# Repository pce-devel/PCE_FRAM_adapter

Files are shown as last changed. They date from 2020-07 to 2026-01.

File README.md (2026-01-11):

# FRAM converter boards

The PC Engine series of systems has a different game-save storage system than most people
these days have gotten used to.  It used a 2KB static RAM.  This wasn't in the cartridges
themselves; initially, it was sold as pat of an add-on to the system: The Tennokoe 2,
"Voice from Heaven".  In later systems like the Duo series, it would be integrated into
the system unit, yet still be limited to 2KB static RAM.

You're probably thinking, "Static RAM is volatile - it loses its contents when the power
is shut off", and you'd be right.  There really weren't any non-volatiole options at the
time.  Instead, they used batteries or large capacitors to apply continuous power to the
memory, so that it would not lose its contents.  In the case of the Tennokoe 2, 2 "AA"
cells were used; in the case of the Duo, a large capacitor was used.

I have lost a few game saves on my Duo because I failed to turn the system on for a period
of time long enough to lose its contents... probably about 1 to 2 weeks.

Because of this, I was inspired to replace the SRAM with modern FeRAM to make it
non-volatile.  But the Duo is a tighter-packed PC board with surface-mount chips, so I felt it
was easier to first test the idea on the Tennokoe 2, which uses a DIP SRAM chip.

I have followed up with a design for a flex PCB to use with surface-mount chips in order to
be suitable for my Duo, and it also works well.

I chose to use the Cypress FM16W08 chip, which can handle 5V, has timing which is
equal to or better than the SRAM it is replacing, and has a similar pinout.  But I still
needed to make adapter boards (which is what this repository is all about).

As the FeRAM is rated for 100 trillion read/write cycles, there is no
concern about lifetime under the usage in this application.

I designed the boards using the free version of EAGLE (2-layer, less than 100mm
on both X- and Y-axes).  The gerbers are included in this repository, in case you
want to get your own set made.

## Assembly/installation instructions for the FRAM-DIP board for the Tennokoe 2:

https://github.com/dshadoff/PCE_FRAM_adapter/blob/master/FRAM-DIP-assembly.md

## Assembly/installation instructions for the FRAM-SOIC board for the Duo and other machines:

https://github.com/dshadoff/PCE_FRAM_adapter/blob/master/FRAM-SOIC-assembly.md

## UPDATE: A new board for use with the PCE Shuttle Backup Memory

The Shuttle's board was designed using KiCAD. While this board is separate and distinct from
the board for the Tennokoe 2, the installation instructions are similar (sorry, but I don't
have pictures)

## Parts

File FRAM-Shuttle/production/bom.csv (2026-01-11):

Designator | Footprint | Quantity | Value | LCSC Part #
J1 | PinHeader_2x03_P2.00mm_Vertical | 1 | Conn_02x03_Odd_Even
R1, R2 | 0805 | 2 | 100K
U1 | SOIC-28W_7.5x17.9mm_P1.27mm | 1 | FM16W08-SG
U2 | DIP-24_18.0mmx34.29mm_W15.24mm | 1 | 6116

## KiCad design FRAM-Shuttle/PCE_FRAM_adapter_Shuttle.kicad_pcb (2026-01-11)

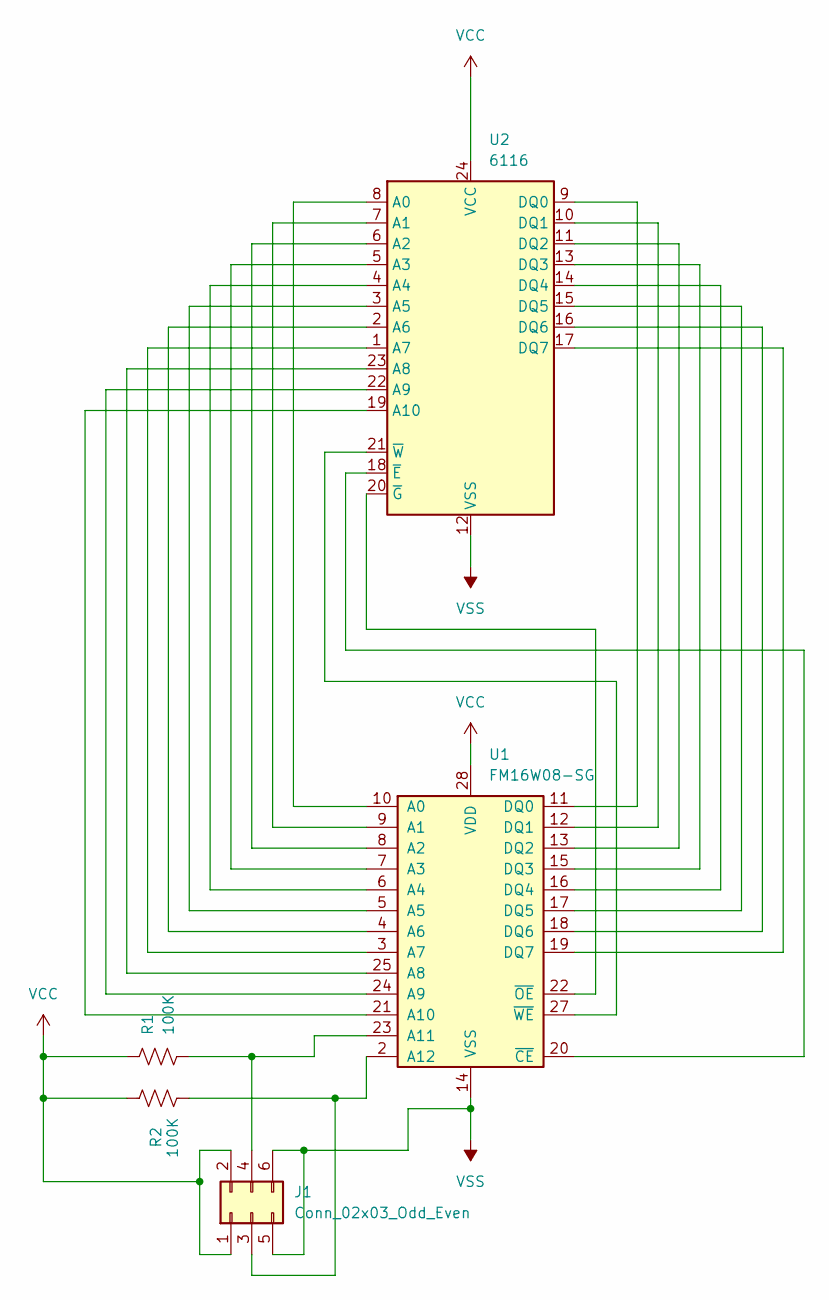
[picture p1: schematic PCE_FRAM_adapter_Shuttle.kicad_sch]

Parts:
J1: Conn_02x03_Odd_Even; PinHeader_2x03_P2.00mm_Vertical
R1, R2: 100K; R_0805_2012Metric_Pad1.20x1.40mm_HandSolder
U1: FM16W08-SG; SOIC-28W_7.5x17.9mm_P1.27mm
U2: 6116; DIP-24_18.0mmx34.29mm_W15.24mm

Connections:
unnamed: J1.3, R2.2, U1.2 (A12)
unnamed: J1.4, R1.2, U1.23 (A11)
unnamed: U1.10 (A0), U2.8 (A0)
unnamed: U1.9 (A1), U2.7 (A1)
unnamed: U1.8 (A2), U2.6 (A2)
unnamed: U1.7 (A3), U2.5 (A3)
unnamed: U1.6 (A4), U2.4 (A4)
unnamed: U1.5 (A5), U2.3 (A5)
unnamed: U1.4 (A6), U2.2 (A6)
unnamed: U1.3 (A7), U2.1 (A7)
unnamed: U1.25 (A8), U2.23 (A8)
unnamed: U1.24 (A9), U2.22 (A9)
unnamed: U1.21 (A10), U2.19 (A10)
unnamed: U1.11 (DQ0), U2.9 (DQ0)
unnamed: U1.12 (DQ1), U2.10 (DQ1)
unnamed: U1.13 (DQ2), U2.11 (DQ2)
unnamed: U1.15 (DQ3), U2.13 (DQ3)
unnamed: U1.16 (DQ4), U2.14 (DQ4)
unnamed: U1.17 (DQ5), U2.15 (DQ5)
unnamed: U1.18 (DQ6), U2.16 (DQ6)
unnamed: U1.19 (DQ7), U2.17 (DQ7)
unnamed: U1.20 (~CE), U2.18 (~E)
unnamed: U1.22 (~OE), U2.20 (~G)
unnamed: U1.27 (~WE), U2.21 (~W)
VCC: J1.1, J1.2, R1.1, R2.1, U1.28 (VDD), U2.24 (VCC)
VSS: J1.5, J1.6, U1.14 (VSS), U2.12 (VSS)

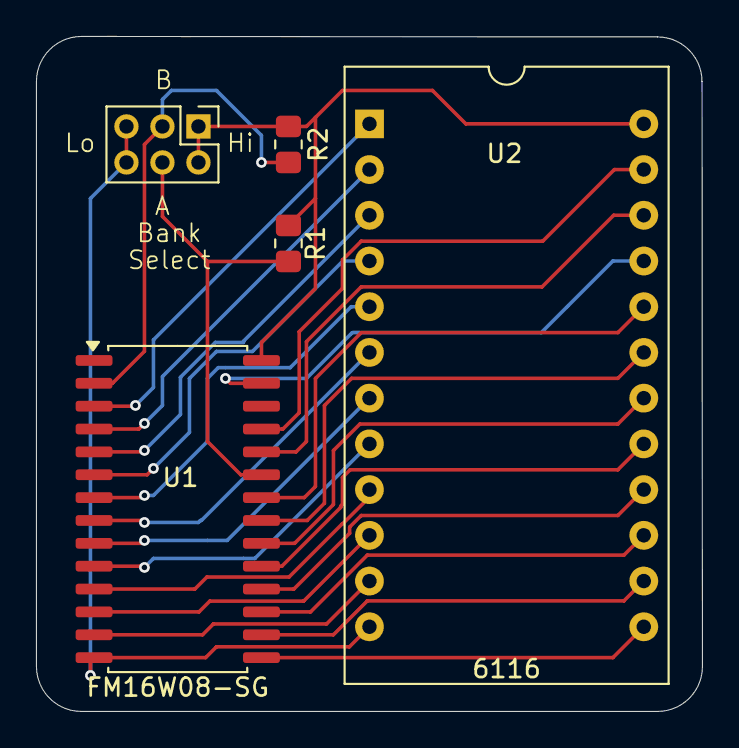
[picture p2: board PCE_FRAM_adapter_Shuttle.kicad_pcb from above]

Board: 2 copper layers, 37.0 x 37.5 mm, 5 parts (0 on the bottom side), 26 nets.

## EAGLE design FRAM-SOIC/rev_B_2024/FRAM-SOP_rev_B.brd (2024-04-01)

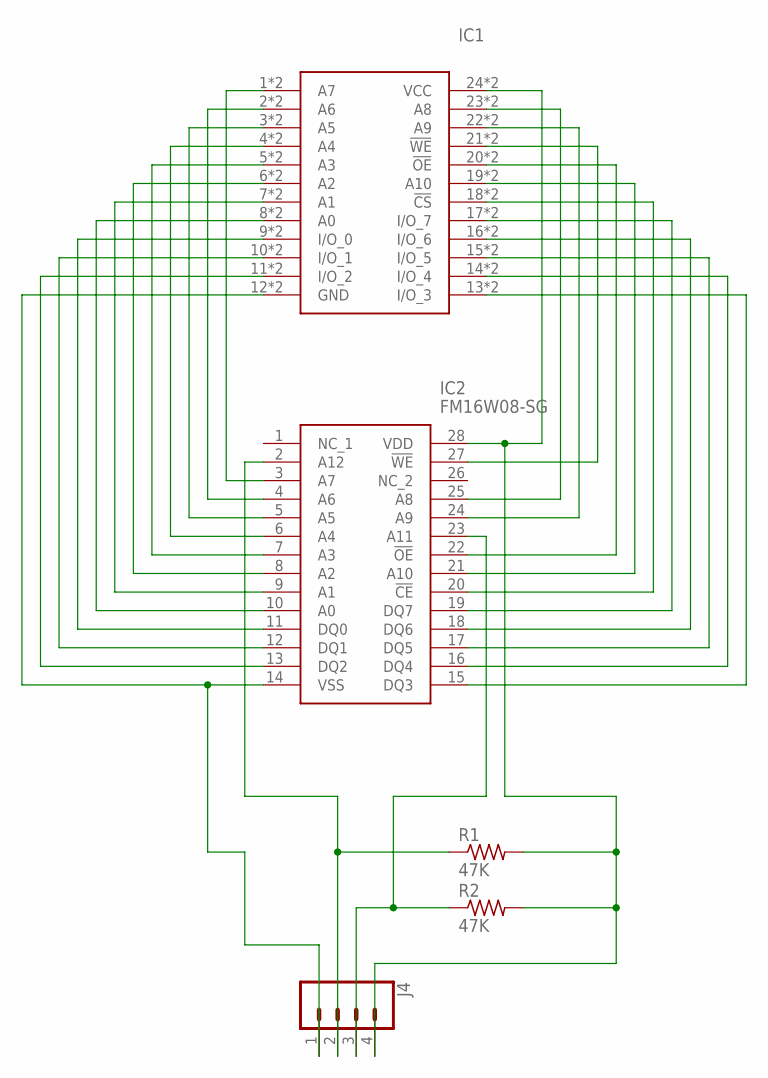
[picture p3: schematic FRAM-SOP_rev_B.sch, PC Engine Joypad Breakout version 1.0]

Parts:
IC1: 6116SOP-CASTELL; CASTELL_SOIC-24N
IC2: FM16W08-SG; SOIC127P1032X267-28N
J4: CONN_04SMD_RA_FEMALE; 1X04_SMD_RA_FEMALE
R1, R2: 47K; R0603

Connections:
unnamed: IC1.24 (VCC), IC1.P$24 (VCC), IC2.28 (VDD), J4.4, R1.2, R2.2
unnamed: IC1.23 (A8), IC1.P$23 (A8), IC2.25 (A8)
unnamed: IC1.22 (A9), IC1.P$22 (A9), IC2.24 (A9)
unnamed: IC1.21 (!WE), IC1.P$21 (!WE), IC2.27 (!WE)
unnamed: IC1.20 (!OE), IC1.P$20 (!OE), IC2.22 (!OE)
unnamed: IC1.19 (A10), IC1.P$19 (A10), IC2.21 (A10)
unnamed: IC1.18 (!CS), IC1.P$18 (!CS), IC2.20 (!CE)
unnamed: IC1.17 (I/O_7), IC1.P$17 (I/O_7), IC2.19 (DQ7)
unnamed: IC1.16 (I/O_6), IC1.P$16 (I/O_6), IC2.18 (DQ6)
unnamed: IC1.15 (I/O_5), IC1.P$15 (I/O_5), IC2.17 (DQ5)
unnamed: IC1.14 (I/O_4), IC1.P$14 (I/O_4), IC2.16 (DQ4)
unnamed: IC1.13 (I/O_3), IC1.P$13 (I/O_3), IC2.15 (DQ3)
unnamed: IC1.1 (A7), IC1.P$1 (A7), IC2.3 (A7)
unnamed: IC1.2 (A6), IC1.P$2 (A6), IC2.4 (A6)
unnamed: IC1.3 (A5), IC1.P$3 (A5), IC2.5 (A5)
unnamed: IC1.4 (A4), IC1.P$4 (A4), IC2.6 (A4)
unnamed: IC1.5 (A3), IC1.P$5 (A3), IC2.7 (A3)
unnamed: IC1.6 (A2), IC1.P$6 (A2), IC2.8 (A2)
unnamed: IC1.7 (A1), IC1.P$7 (A1), IC2.9 (A1)
unnamed: IC1.8 (A0), IC1.P$8 (A0), IC2.10 (A0)
unnamed: IC1.9 (I/O_0), IC1.P$9 (I/O_0), IC2.11 (DQ0)
unnamed: IC1.10 (I/O_1), IC1.P$10 (I/O_1), IC2.12 (DQ1)
unnamed: IC1.11 (I/O_2), IC1.P$11 (I/O_2), IC2.13 (DQ2)
unnamed: IC2.2 (A12), J4.2, R1.1
unnamed: IC1.12 (GND), IC1.P$12 (GND), IC2.14 (VSS), J4.1
unnamed: IC2.23 (A11), J4.3, R2.1

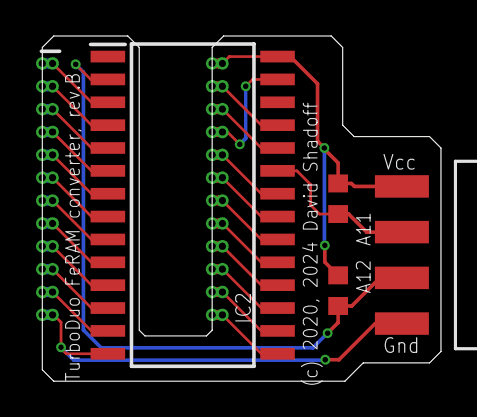
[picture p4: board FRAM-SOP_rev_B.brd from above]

Board: 2 copper layers, 22.1 x 19.2 mm, 5 parts (0 on the bottom side), 26 nets.

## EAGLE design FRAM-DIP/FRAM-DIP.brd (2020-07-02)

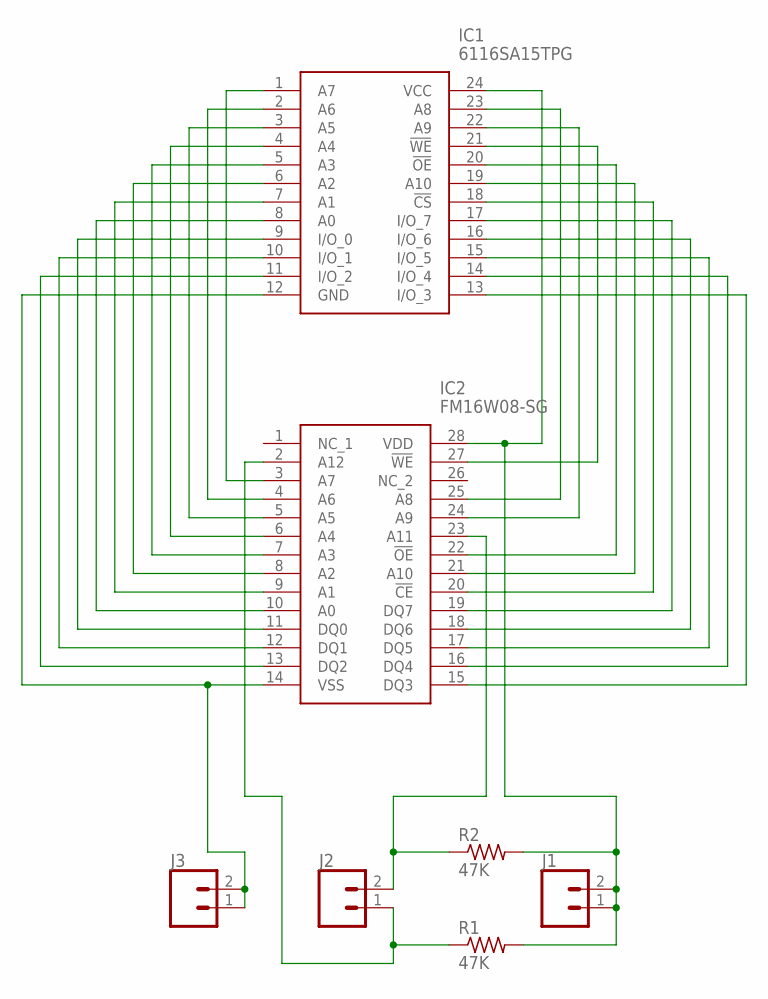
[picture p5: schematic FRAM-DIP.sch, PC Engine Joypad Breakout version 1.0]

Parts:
IC1: 6116SA15TPG; DIP864W51P254L3169H381Q24N
IC2: FM16W08-SG; SOIC127P1032X267-28N
J1, J2, J3: CONN_02; 1X02
R1, R2: 47K; R0805

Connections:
unnamed: IC1.24 (VCC), IC2.28 (VDD), J1.1, J1.2, R1.2, R2.2
unnamed: IC1.23 (A8), IC2.25 (A8)
unnamed: IC1.22 (A9), IC2.24 (A9)
unnamed: IC1.21 (!WE), IC2.27 (!WE)
unnamed: IC1.20 (!OE), IC2.22 (!OE)
unnamed: IC1.19 (A10), IC2.21 (A10)
unnamed: IC1.18 (!CS), IC2.20 (!CE)
unnamed: IC1.17 (I/O_7), IC2.19 (DQ7)
unnamed: IC1.16 (I/O_6), IC2.18 (DQ6)
unnamed: IC1.15 (I/O_5), IC2.17 (DQ5)
unnamed: IC1.14 (I/O_4), IC2.16 (DQ4)
unnamed: IC1.13 (I/O_3), IC2.15 (DQ3)
unnamed: IC1.1 (A7), IC2.3 (A7)
unnamed: IC1.2 (A6), IC2.4 (A6)
unnamed: IC1.3 (A5), IC2.5 (A5)
unnamed: IC1.4 (A4), IC2.6 (A4)
unnamed: IC1.5 (A3), IC2.7 (A3)
unnamed: IC1.6 (A2), IC2.8 (A2)
unnamed: IC1.7 (A1), IC2.9 (A1)
unnamed: IC1.8 (A0), IC2.10 (A0)
unnamed: IC1.9 (I/O_0), IC2.11 (DQ0)
unnamed: IC1.10 (I/O_1), IC2.12 (DQ1)
unnamed: IC1.11 (I/O_2), IC2.13 (DQ2)
unnamed: IC2.2 (A12), J2.1, R1.1
unnamed: IC2.23 (A11), J2.2, R2.1
unnamed: IC1.12 (GND), IC2.14 (VSS), J3.1, J3.2

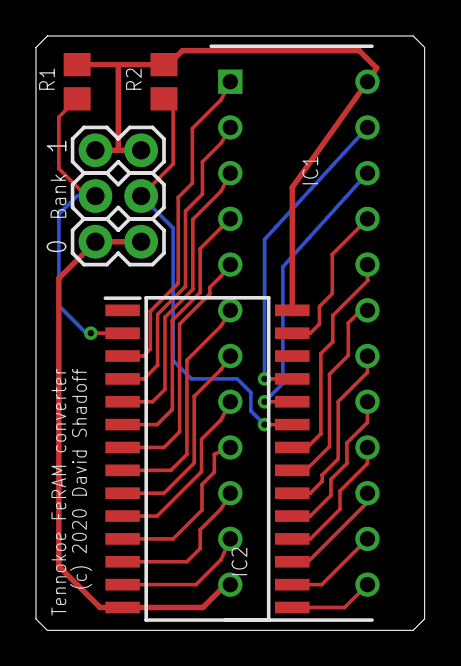
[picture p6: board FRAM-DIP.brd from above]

Board: 2 copper layers, 21.6 x 33.0 mm, 7 parts (0 on the bottom side), 26 nets.

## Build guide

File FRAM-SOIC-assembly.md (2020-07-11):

# FRAM-SOIC converter board installation - TurboDuo

I only have a Duo to demonstrate on, but I'm reasonably certain that the board will fit
other models like the Duo-R and Duo-RX.

The SOIC adapter board is simple enough to install if you are confident in your soldering
skills. But if you are just starting out, you may want to get it installed by somebody
else.

## Preparation:

1. Backup - If you have any game saves in the unit, you will want to back them up somehow.
A Tennokoe Bank card is probably your best option.

2. Open the Machine - Next, turn the unit over, and remove the screws holding the back on.
After removing the screws, turn the Duo back over so it sits as it normally would.  Next,
open the CD lid, and gently wiggle the top plastic shell off of the bottom shell... you may
see that some plastic in the CD drive area; this may be helpful to get some leverage for
gently opening the top (be careful not to touch the lens !)  Also, if your system has had
modifications done on it before, there may be wires leading to some mounting point in the
top shell; be very careful not to put any stress on these as you lift the top shell.

3. Locate the Chip - On the Duo, you will find the SRAM chip in the middle on the
left-right axis, and slightly toward the back on the front-back axis.  It's close to the
voltage regulators with their heatsinks.

Take note of where pin 1 of the chip is.

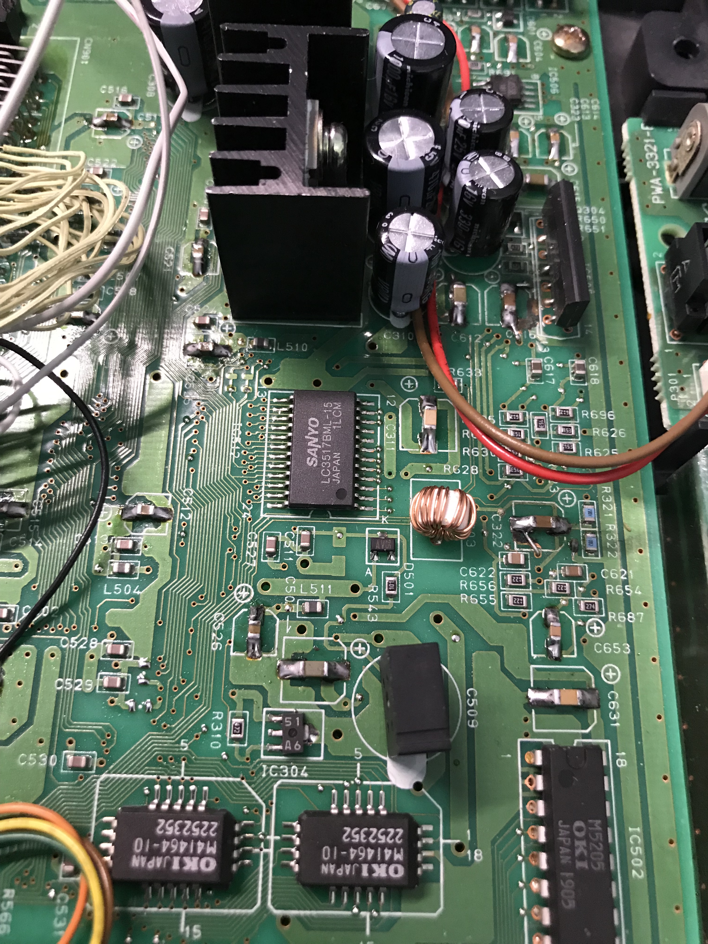
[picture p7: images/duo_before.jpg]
SRAM on Duo


## Desolder the old chip:

This is the most difficult part of the operation, as the chip seems to be held
tightly against the board by some sort of lacquer or glue - and this is why I don't
recommend this upgrade to novices.

1. If you have a hot air station, you may wish to use it to desolder the pins - and weaken
the lacquer/glue bond.

2. If you don't have a hot air station, you should first remove as much solder as possible
from the leads, using a solder wick. As you apply heat on a second pass, you will need to
lift the pins from the pads as well.  Removing the actual chip from the board may require
isopropyl alcohol, but as you try to lift it, be careful not to damage the board or any of
the copper traces !  Once it's off, go back around the pads with the solder wick to clean
them up, and use the alcohol once more to clean the area.

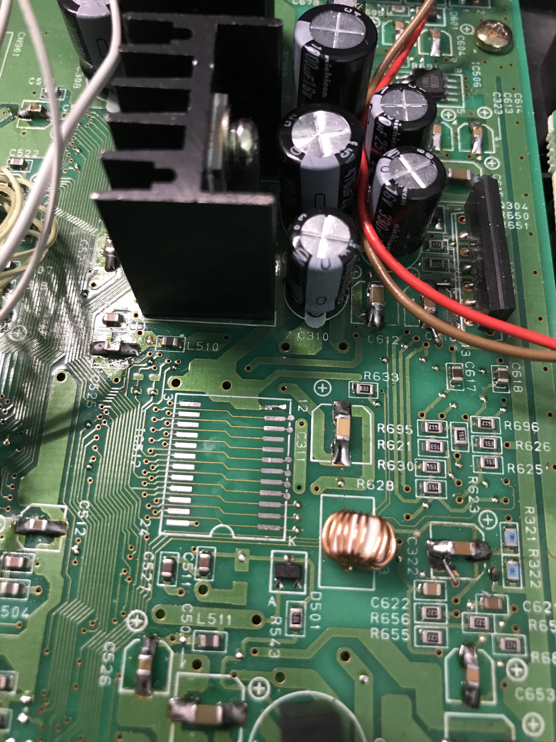
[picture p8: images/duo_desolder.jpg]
SRAM removed


## Apply the Flex PC Board:

1. You'll notice that the Duo PC board has some exposed via's; although the flex PC board
doesn't expose any traces, I felt it was better to lay down a strip of Kapton tape, just
in case.

2. Position the flex PC board as shown in the photo below, with the "U" of the board facing
pin 1's end. As the board is a little tricky to position, and shifts easily, I used another
pice of Kapton tape to position it and hold it in position as I soldered.  Be careful to
ensure that the felx PC board's castellations and inset via hole are both on the corresonding
SMD trace, and that they make a good solid connection when soldered.

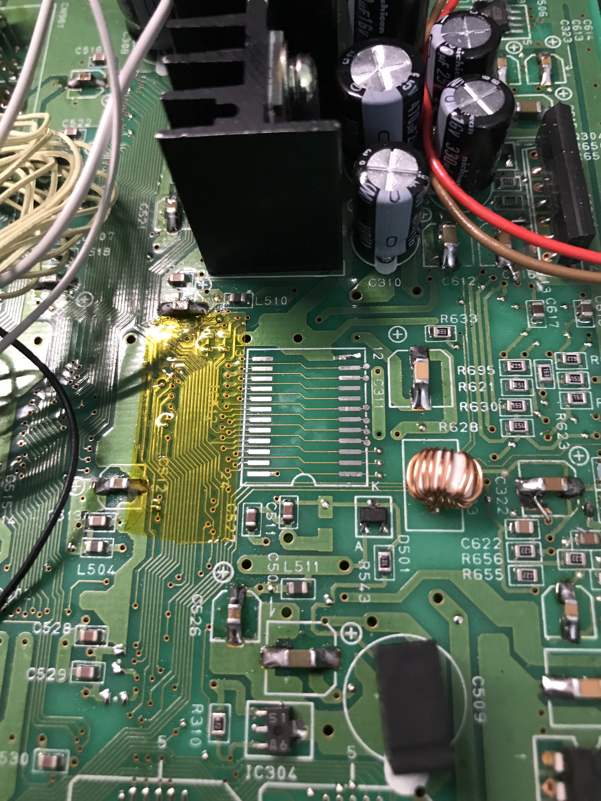
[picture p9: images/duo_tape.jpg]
Ready to solder

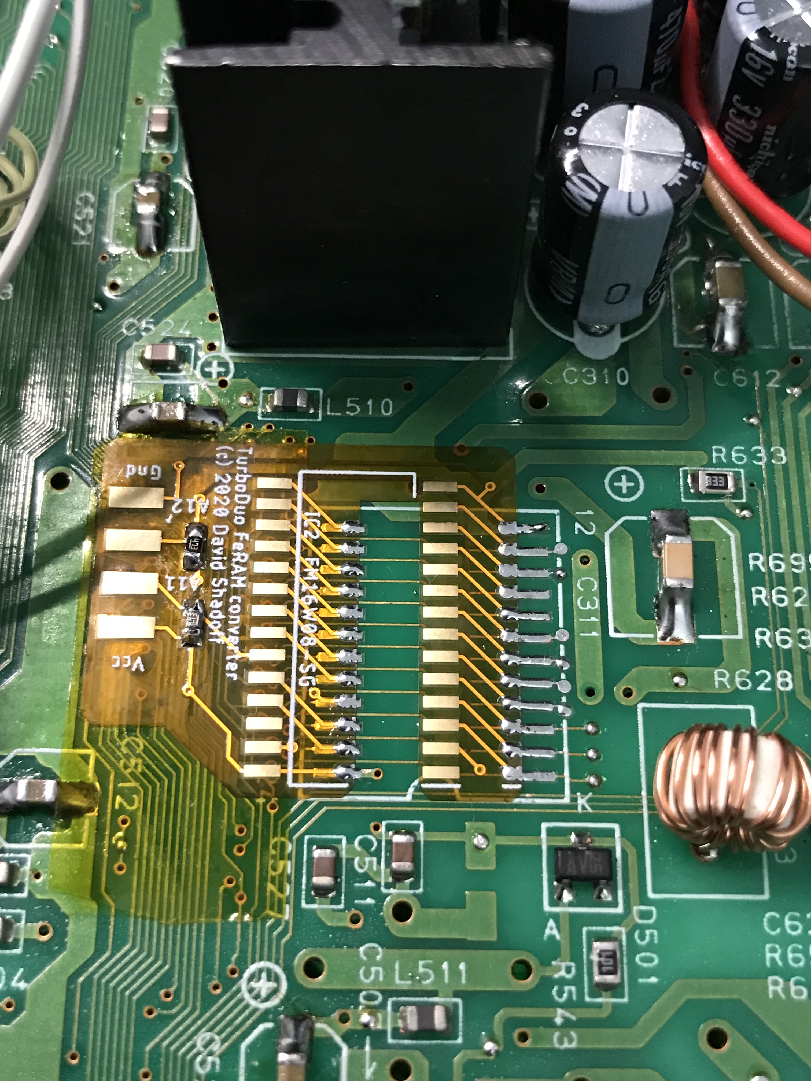
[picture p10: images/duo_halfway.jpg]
Soldered in place


## Solder the FeRAM chip:

1. You have a couple of choices before mounting the FRAM chip - you should decide whether
you are just planning to have a single backup RAM storage area, or whether you would like
as many as four (since the chip's capacity is that large).  In either case, you should solder
the two 47K pull-up resistors on the board.  We'll get to the choice in a moment.

2. Position the FeRAM carefully on the board, and be careful to ensure the correct
orientation for pin 1.  Solder in place (I'm assuming that you've soldered a similar SMD
device in the past)

3. Now for the choice.  In my case, I was only intersted in replacing the original, single
BRAM area, so I was done at this point.  However, if you want more, you will need to create
some sort of switching setup.  On the left edge of the board, you will notice a series of
four solder tabs: the outer tabs are for ground and Vcc (logical states '0' and '1'); the
middle two pads are for selecting the bank. The pull-up resistors bring these pins to the
'1'/'1' state automatically, so really you only need to ground either or both of these
address lines in order to select another bank.  I'll leave the exact type of switch to you.

4. So that you don't leave those tabs (with both ground and power) exposed, you may want to
use another piece of Kapton to cover that flap and anchor it to the board.

5. Before reassembling the case completly, you might want to test it out.  If you have a
Tennokoe Bank card, this should be a good option - restore something to its memory, turn
the power off, then try it out again after a few minutes, to make sure that the memory is
non-volatile.

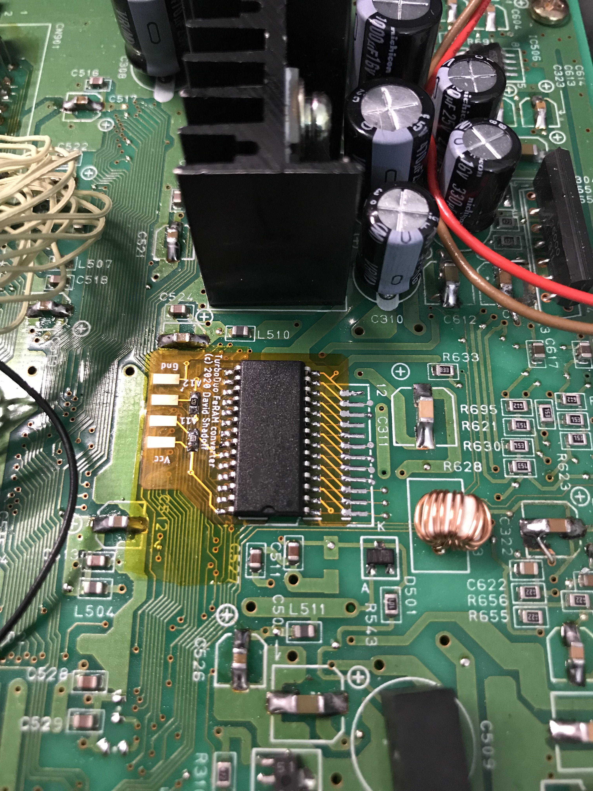
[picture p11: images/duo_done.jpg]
DONE !!


## You're Done !!

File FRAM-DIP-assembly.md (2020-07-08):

# FRAM-DIP converter board installation

The DIP board is simple enough to assemble if you have basic soldering skills. But there
are a few important points to follow.

## Assemble the module:

1. Start by preparing the 2 12-pin headers: the pins need to be pushed downward so that
no metal whatsoever protrudes through the top of the board when fitted. If you run your
finger along the solder pads, you shouldn't be able to feel the pins.  It's OK for the
pins to be slightly inset from the edge, but not too much. I ordered a 1.6mm thickness
PC board, so this made it easier to adjust (thinner would be more difficult).

2. Once all the pins are adjusted to the right length, the easiest way to keep the board
stable while mounting is to insert the headers into a solderless breadboard, and place
the board on top.  Once positioned, solder the pins into the holes until the solder
level is flush with the board. As with any solder joint, flux is your friend. I use a
flux pen for connections on boards like these.

3. Next, solder the pull-up resistors and/or jumpers or switching wires.  I placed two
47K ohm 0805 surface-mount resistors on the board to ensure that the two floating address
lines are set to something.  The jumpers are there in case you would like to occasionally
switch which bank is active (the FeRAM chip contains 4 times as much memory as the SRAM
which it replaces).  For my uses, I only wanted to use a single bank. I have set up the
board so that you can switch banks by jumper, but you could adapt it to some sort of
switch if you prefer. Just remember that it's the two middle holes which need to be
switched between logical high or low values.

4. Next, the surface-mount FeRAM chip is to be mounted. BE CAREFUL TO ORIENT PIN 1 PROPERLY !!
On a chip like this, I would align it and hold it in place while soldering one corner pin.
Then, ensuring continuing good alignment, my other hand can be freed up for more conistent
solder joints.  Careful not to overheat the chip... but I expect that you already knew that.

5. Clean the board with 99% isopropyl, and it's ready to mount.

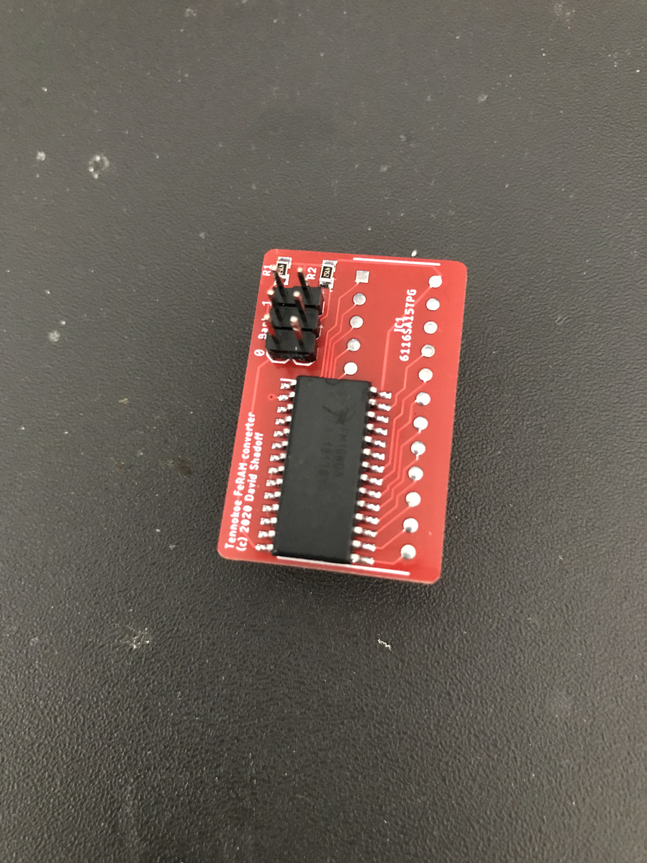
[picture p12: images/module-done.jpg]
Finished Module


## Desolder the chip from the Tennokoe 2:

1. If you have any game saves in the unit, you will want to back them up somehow. A
Tennokoe Bank card is probably your best option.  Next, remove the batteries from the
unit, and remove the screws holding the back of the unit on.  Once the system is open,
gently move the case to the side; the battery leads are still connected. After this
operation, you won't need the battery anymore, but I still like to leave them connected.

2. Locate the SRAM chip, and identify pin 1 (there is a notch on one end identifying it).
Turn over the board, and use a solder wick the rmove the solder from around each of the
leads. Since this is a one-layer PC board, once you wick the solder away from the pad all
the way around each lead, they move somewhat freely. In both case where I have done this,
this is all that is needed to be able to extract the chip as it moves freely. But pay
attention to any pins which might still have some solder on them.

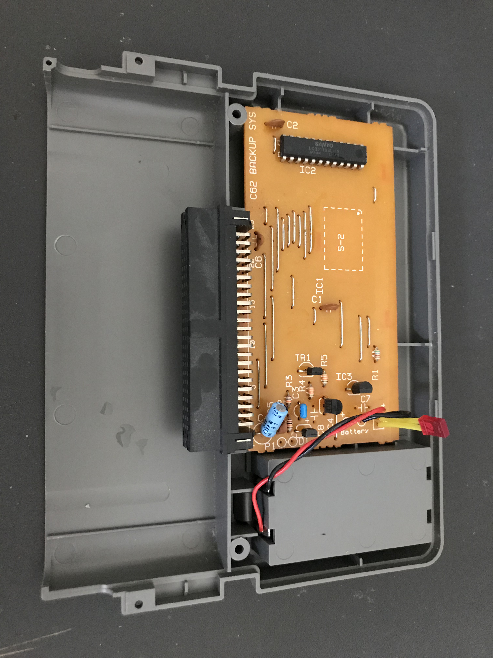
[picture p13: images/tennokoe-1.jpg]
Take the cover off

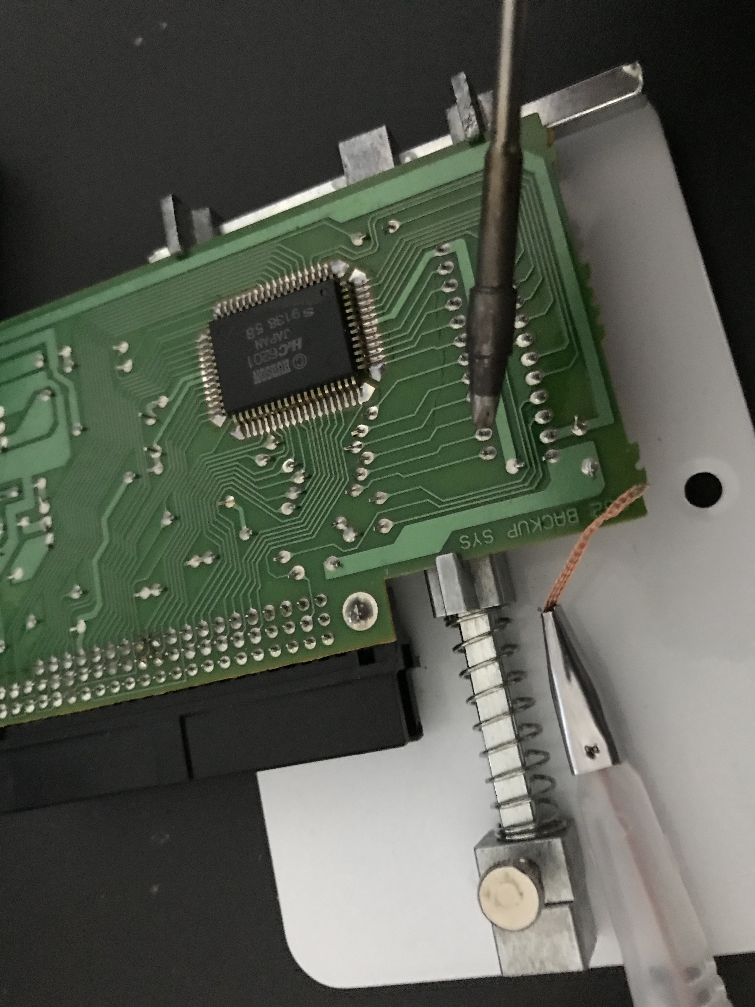
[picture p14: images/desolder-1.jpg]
Ready to desolder

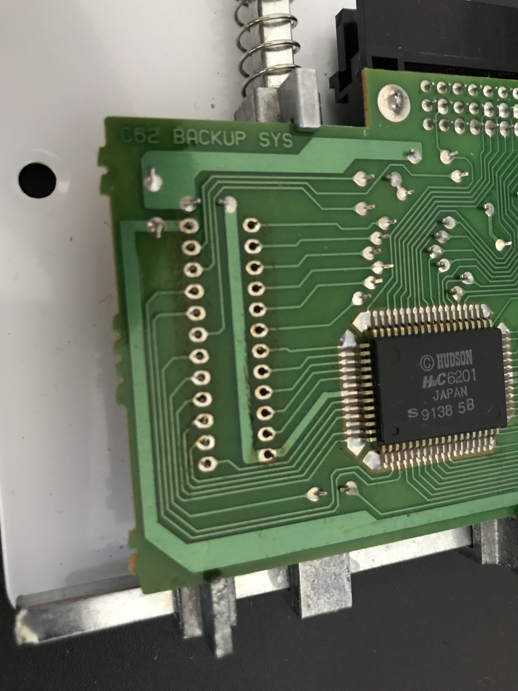
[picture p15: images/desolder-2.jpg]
Chip is now removed

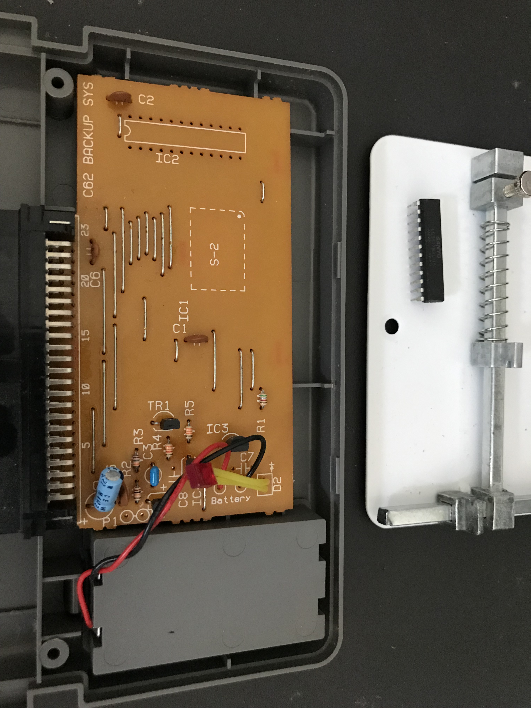
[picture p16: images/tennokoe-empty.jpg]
Empty socket


## Replace the empty spot with the module you built earlier:

1. Once fully removed, you can insert the assembled module. PAY CAREFUL ATTENTION TO THE
ORIENTATION OF PIN 1 !!  You will want to cut the header pins closer to the board, as
they extend quite a distance beyond the board... but be careful to leave a small amount
of pin protruding, in order to get a good solder joint (being a 1-layer board, the solder
won't make a good bond through the hole, as it has on the module you made earlier).

2. Check orientation one more time !   Then solder it in.

3. You might want to test it out before reassembling the case.  If you have a Tennokoe Bank
card, this should be a good option - restore something to its memory, turn the power off,
then try it out again after a few minutes, to make sure that the memory is non-volatile.

4. When reassembling, seat the PC board properly in the back plastic shell; this is a bit
tricky, as it doesn't seem to have an optimal position at first.  When putting the top cover
on, be sure to move the LED into its position in the top case first, before closing the case
and re-fastening the screws.

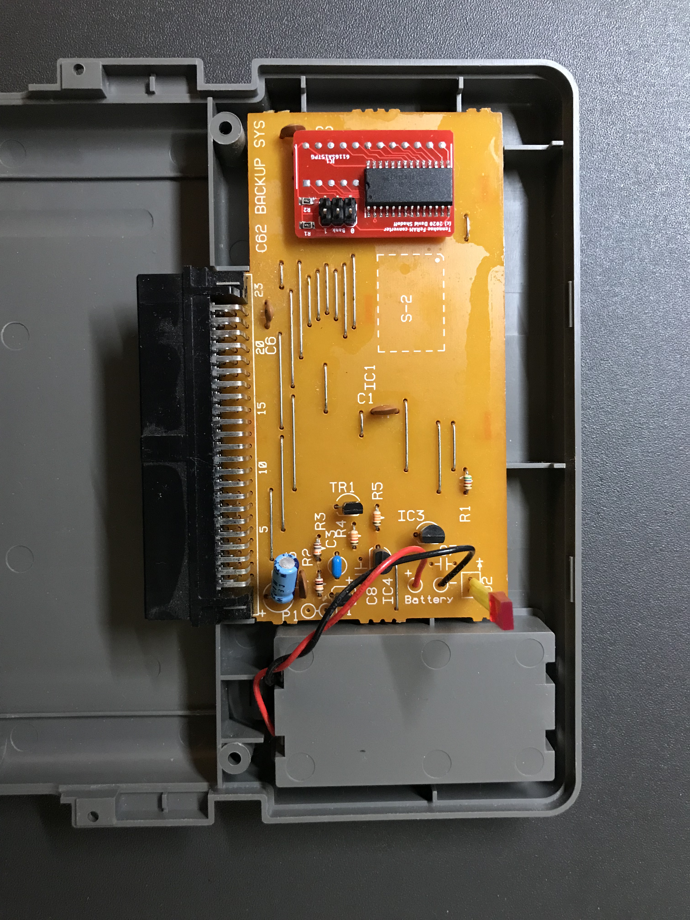
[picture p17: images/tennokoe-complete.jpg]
DONE !!


## You're Done !!

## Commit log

2020-07-02 Initial commit
    Initial commit; board to replace DIP SRAM in Tennokoe 2 unit
    [FRAM-DIP.brd, FRAM-DIP.sch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]
2020-07-11 Add surface-mount version
    A surface-mount version, to support the Duo machine, is added
2020-07-11 Add SOIC board
    [FRAM-SOIC.brd, FRAM-SOIC.sch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]
2024-04-01 Create a new revision of the FRAM SOP board
    [FRAM-SOIC.brd, FRAM-SOIC.sch, FRAM-SOP_rev_B.brd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]
2026-01-11 Add FRAM adapter for PCE Shuttle Backup Memory Unti
    [PCE_FRAM_adapter_Shuttle.kicad_pcb, PCE_FRAM_adapter_Shuttle.kicad_sch, bom.csv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]

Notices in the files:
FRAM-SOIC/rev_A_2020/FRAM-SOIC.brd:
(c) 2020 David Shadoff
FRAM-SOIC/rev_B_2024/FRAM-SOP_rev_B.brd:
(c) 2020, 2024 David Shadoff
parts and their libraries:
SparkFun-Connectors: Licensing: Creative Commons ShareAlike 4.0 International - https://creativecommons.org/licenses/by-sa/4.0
